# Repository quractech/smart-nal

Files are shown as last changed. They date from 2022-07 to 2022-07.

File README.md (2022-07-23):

# smart Nal
Smart Nal enables ON and OFF functionality for LED ceiling lamp using Bluetooth or normal light switch. <br>

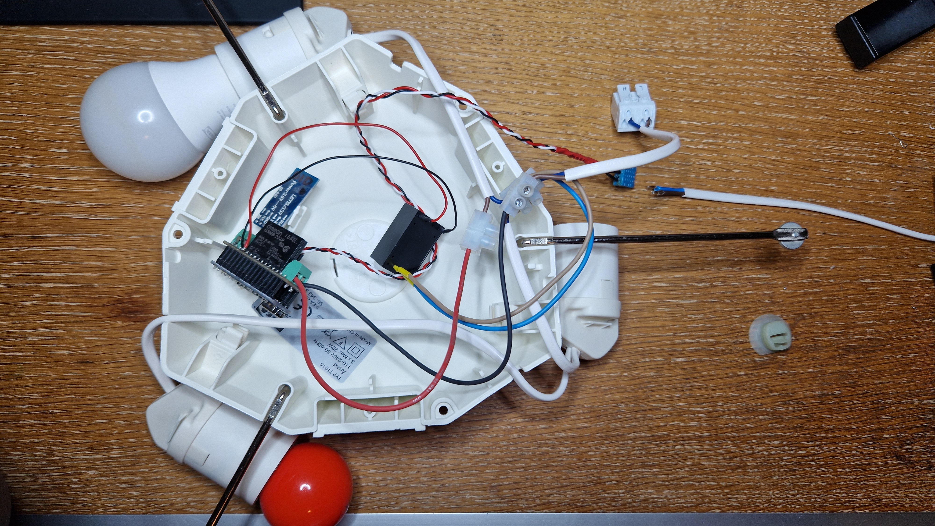
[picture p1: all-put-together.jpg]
image of the Smart Nal Hardware


watch the following YouTube channel for more information. </br>
https://www.youtube.com/embed/videoseries?list=PLivrBlTrqPpaUyPcGpUUAaZgcAJCYTLqt
YouTube Video (https://www.youtube.com/embed/videoseries?list=PLivrBlTrqPpaUyPcGpUUAaZgcAJCYTLqt) </br>

schematic of the Smart Nal Hardware. <br>
https://github.com/quractech/smart-nal/blob/2a30d1d0165a11da4ee4c517b96f4f8cc76464df/smartNal.pdf

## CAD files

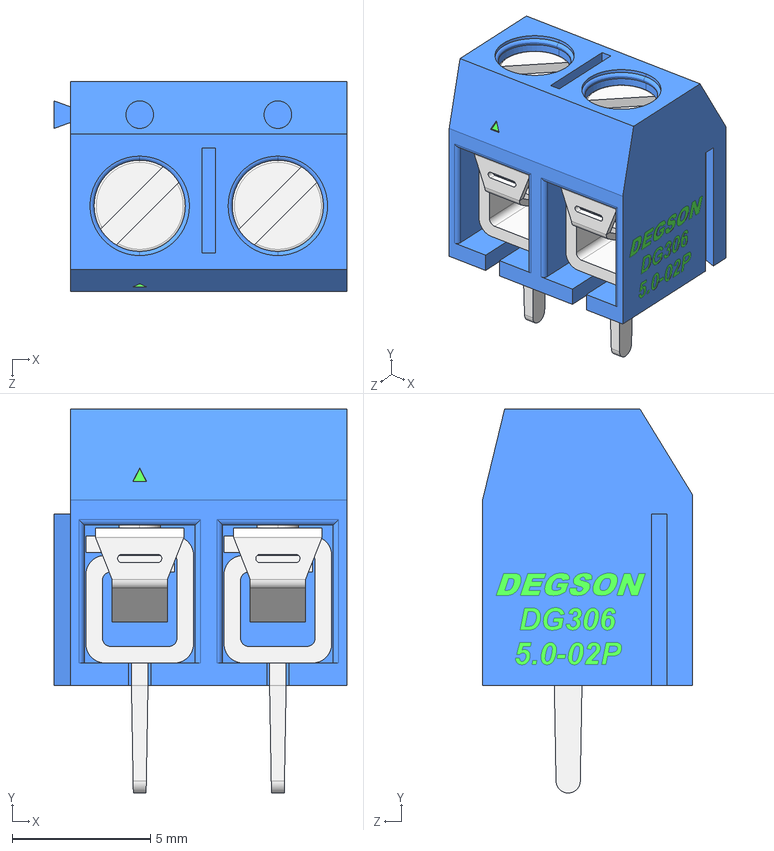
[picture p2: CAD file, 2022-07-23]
Smart Nal/HW/3dModels/DG306-5.0-02P-12-00AH.STEP
10.6 x 13.9 x 7.60 mm

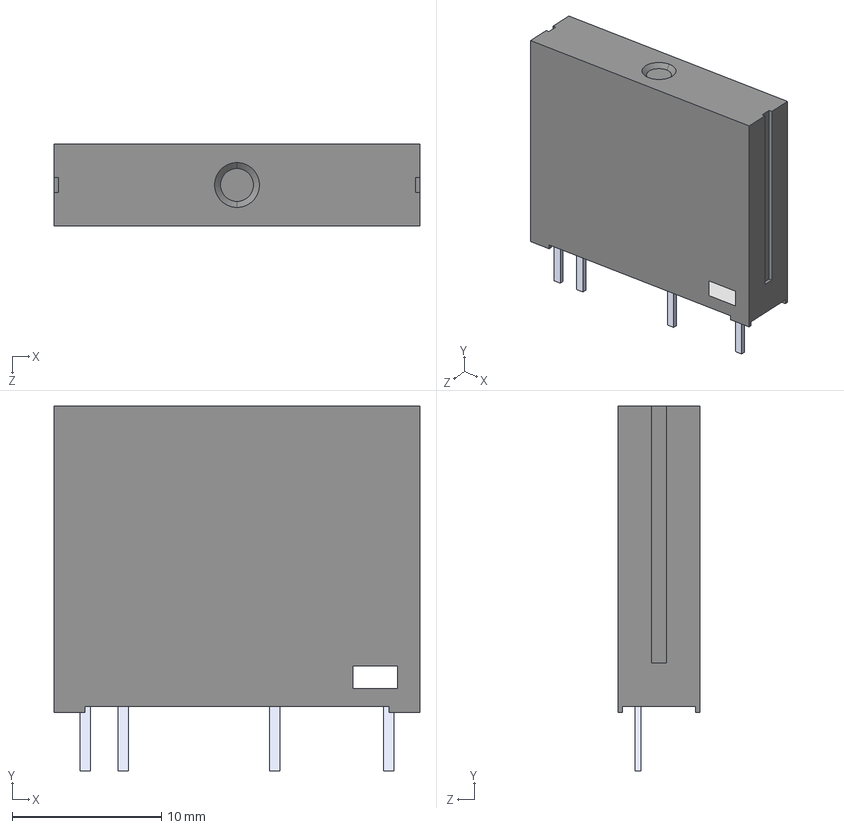
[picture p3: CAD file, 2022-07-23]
Smart Nal/HW/3dModels/G3MB202PDC12.step
24.5 x 24.4 x 5.50 mm

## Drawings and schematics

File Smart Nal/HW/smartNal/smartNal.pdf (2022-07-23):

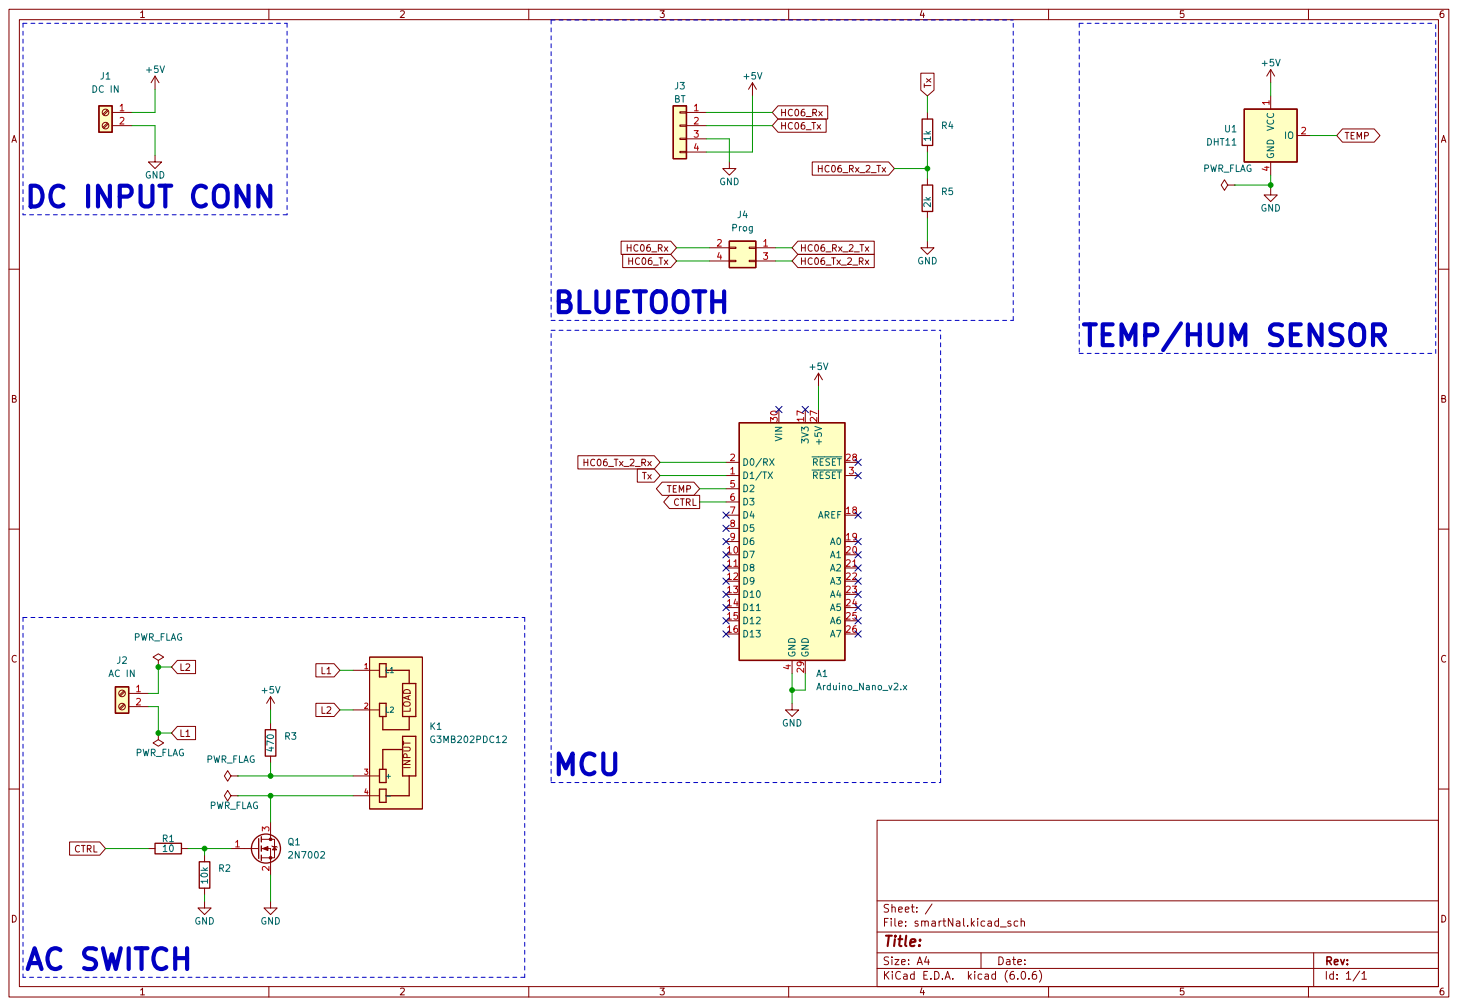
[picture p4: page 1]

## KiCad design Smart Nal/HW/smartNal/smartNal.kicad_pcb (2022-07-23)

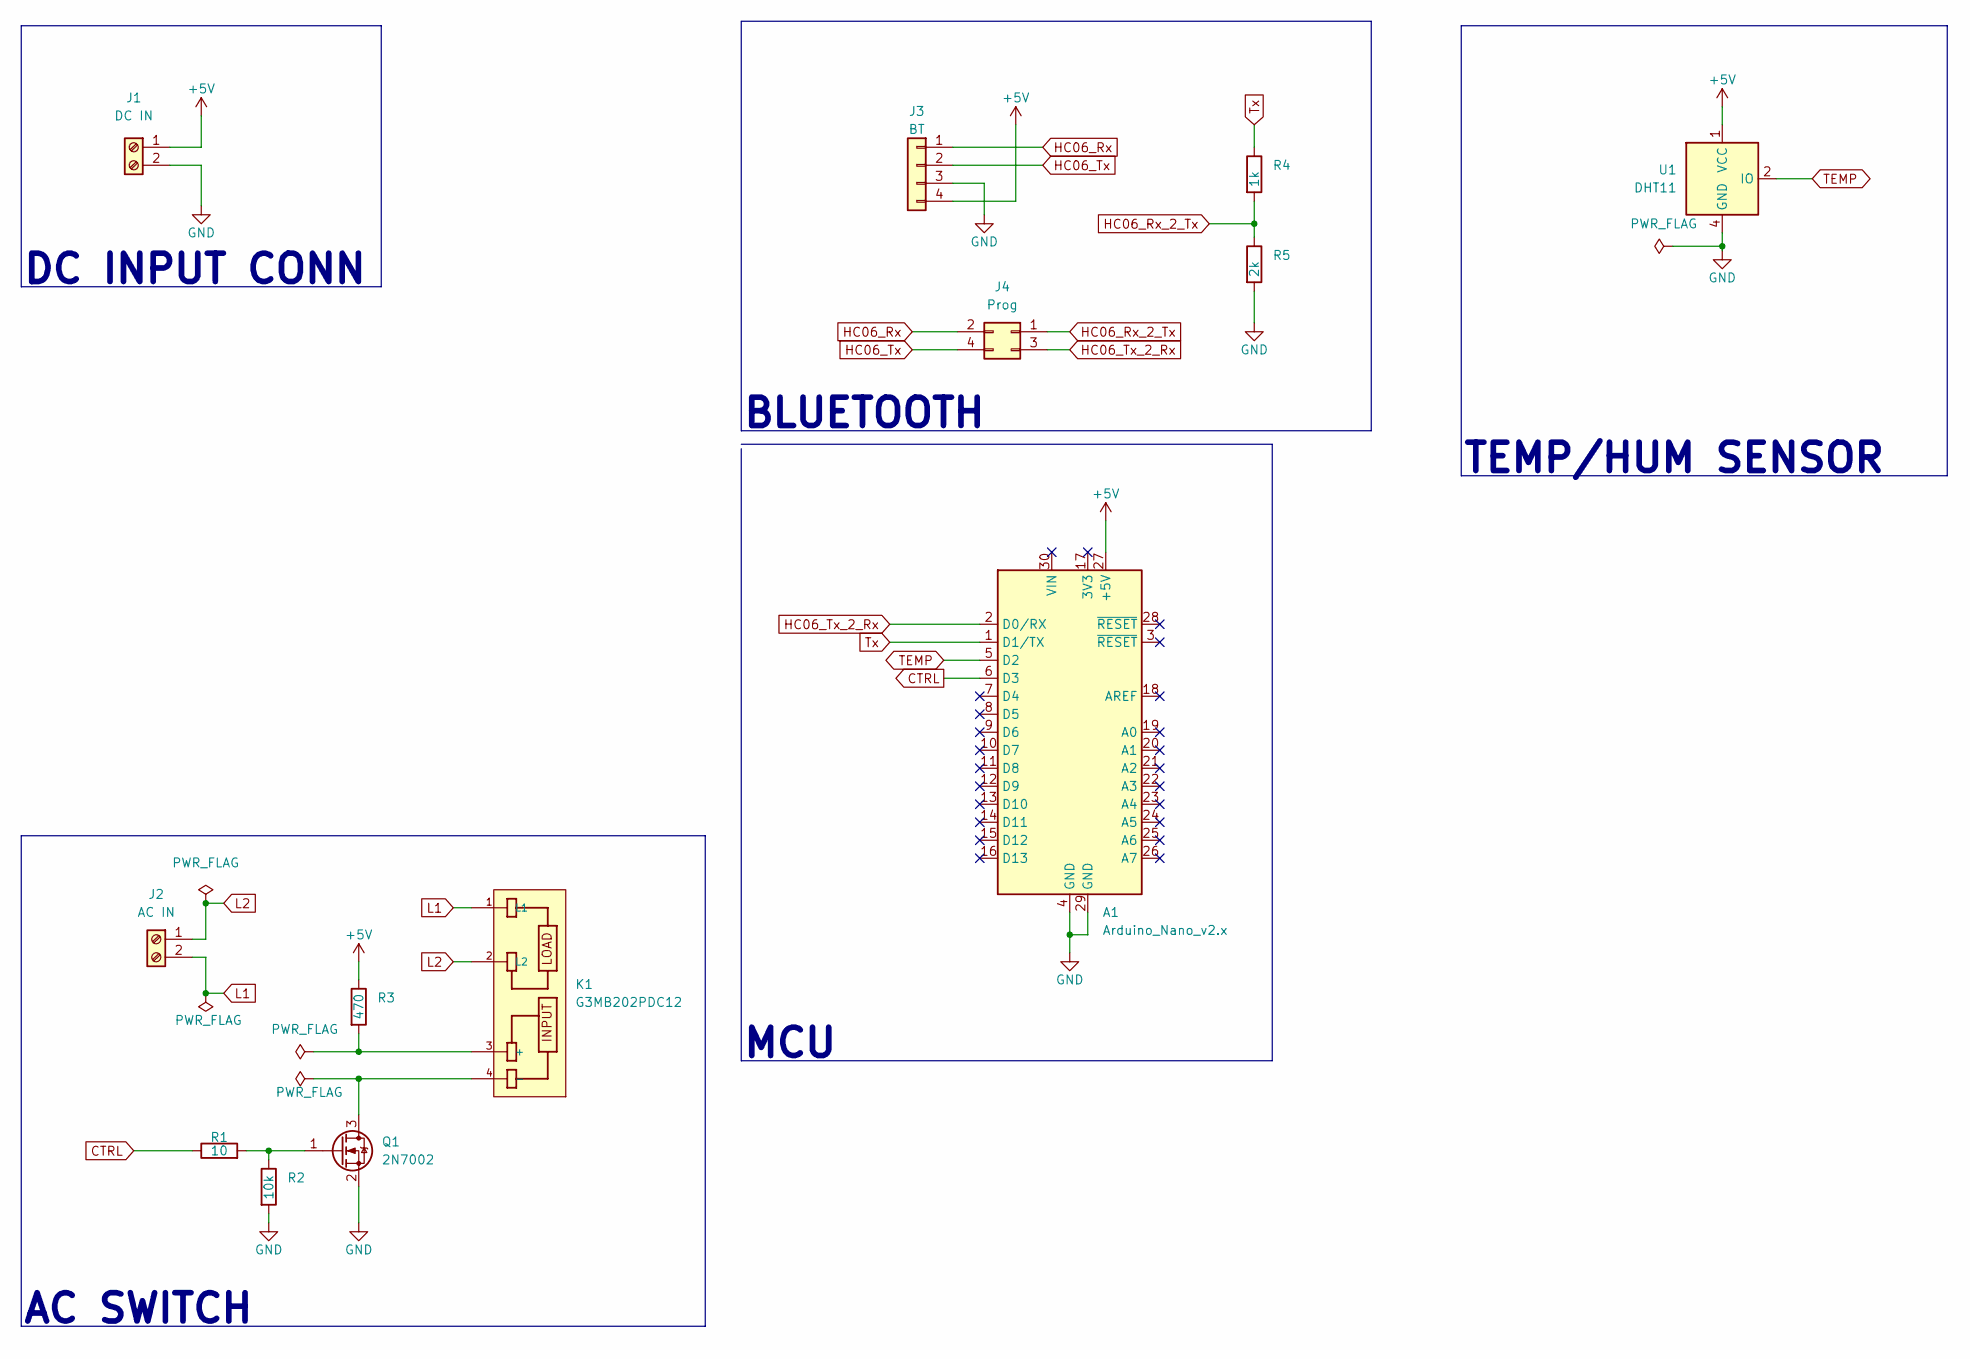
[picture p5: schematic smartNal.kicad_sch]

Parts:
A1: Arduino_Nano_v2.x; Arduino_Nano
J1: DC IN; TerminalBlock_bornier-2_P5.08mm
J2: AC IN; TerminalBlock_bornier-2_P5.08mm
J3: BT; PinHeader_1x04_P2.54mm_Vertical
J4: Prog; PinHeader_2x02_P2.54mm_Vertical
K1: G3MB202PDC12; RELAY_G3MB202PDC12; PARTREV N/A
Q1: 2N7002; SOT-23; MFR.Part # 2N7002; JLCPCB Part # C8545
R1: 10; R_0603_1608Metric
R2: 10k; R_0603_1608Metric
R3: 470; R_0603_1608Metric
R4: 1k; R_0603_1608Metric
R5: 2k; R_0603_1608Metric
U1: DHT11; Aosong_DHT11_5.5x12.0_P2.54mm

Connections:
+5V: A1.27 (+5V), J1.1, J3.4, R3.1, U1.1 (VCC)
CTRL: A1.6 (D3), R1.1
GND: A1.4 (GND), A1.29 (GND), J1.2, J3.3, Q1.2 (S), R2.2, R5.2, U1.4 (GND)
HC06_Rx: J3.1, J4.2
HC06_Rx_2_Tx: J4.1, R4.2, R5.1
HC06_Tx: J3.2, J4.4
HC06_Tx_2_Rx: A1.2 (D0/RX), J4.3
L1: J2.2, K1.1 (L1)
L2: J2.1, K1.2 (L2)
unnamed: K1.3 (+), R3.2
unnamed: K1.4 (-), Q1.3 (D)
unnamed: Q1.1 (G), R1.2, R2.1
TEMP: A1.5 (D2), U1.2 (IO)
Tx: A1.1 (D1/TX), R4.1

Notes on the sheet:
BLUETOOTH
DC INPUT CONN
TEMP/HUM SENSOR
AC SWITCH
MCU

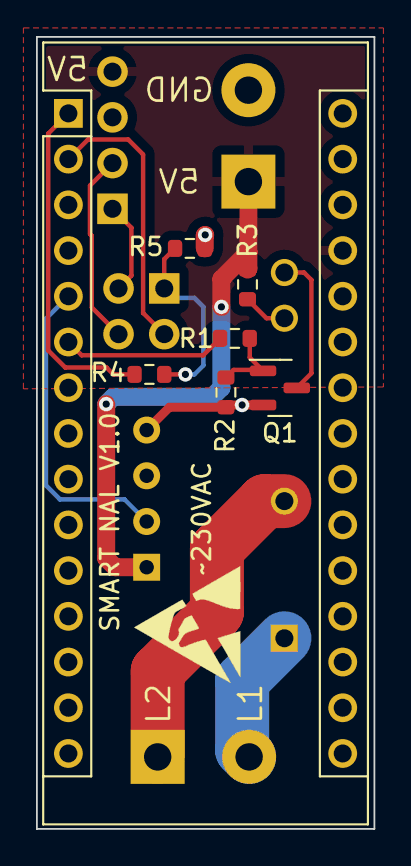
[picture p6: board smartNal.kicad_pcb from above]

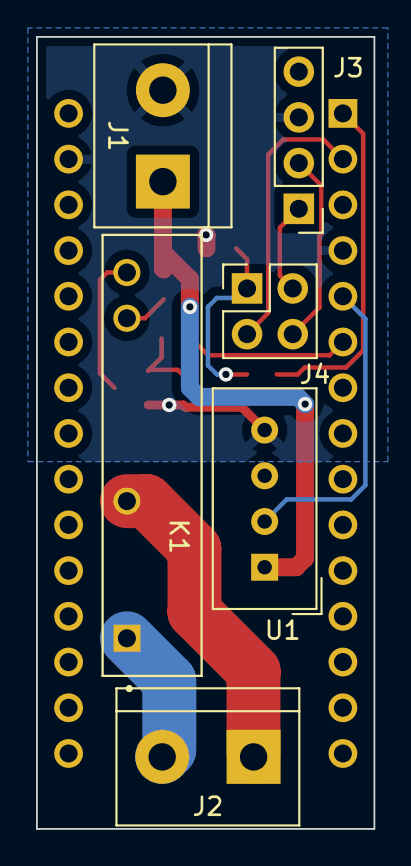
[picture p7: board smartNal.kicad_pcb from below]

Board: 2 copper layers, 18.8 x 44.0 mm, 13 parts (6 on the bottom side), 14 nets.

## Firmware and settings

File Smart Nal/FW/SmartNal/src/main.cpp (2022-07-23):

//#include <Arduino.h>
#include <EEPROM.h>
#include <Adafruit_Sensor.h>
#include <DHT.h>
// #include "LibPrintf.h"
//#include <DHT_U.h>

#define DHTPIN 2 // Digital pin connected to the DHT sensor
//#define DHTTYPE DHT22       // DHT 22  (AM2302), AM2321
#define DHTTYPE DHT11 // DHT 11

#define LEDPin LED_BUILTIN  // Arduino nano buildin LED PIN
#define CTRLPin 3           // Assign D3 to Control
#define EEPROM_ADR 10        // EEPROM ADDRESS 0
#define maxReset 1          // Maximum number of reset

DHT dht(DHTPIN, DHTTYPE);   // Initialize DHT11
volatile uint8_t lightStatus = 0;
volatile unsigned char serialMessage = 0;
volatile uint8_t resetCounter = 0;
float humidityResult = 0;
float tempResult = 0;

void setup()
{
  pinMode(LEDPin, OUTPUT);  // Configure LED Pin as an OUTPUT
  pinMode(CTRLPin, OUTPUT); // Configure controll pin as an OUTPUT
  Serial.begin(9600);        // Start Serial communication
  dht.begin();               // Start DHT11
  digitalWrite(LEDPin, LOW);
  
  resetCounter = EEPROM.read(EEPROM_ADR); // Assign EEPROM value stored in ADDRESS 0 to the variable resetCounter

  resetCounter++;                         // Increament resetCounter
  if (resetCounter > maxReset)
  {
    lightStatus = 1;
    resetCounter = 0;               // set the variable resetCounter to 0
    // digitalWrite(LEDPin, HIGH);
    digitalWrite(CTRLPin, HIGH);
  }
  else
  {
    lightStatus = 0;
    // digitalWrite(LEDPin, LOW);
    digitalWrite(CTRLPin, LOW);
  }
  EEPROM.write(EEPROM_ADR, resetCounter); // Store the new resetCounter to EEPROM
}

void loop()
{
  noInterrupts();
  // critical, time-sensitive code here
  if (lightStatus == 0)
  {
    // digitalWrite(LEDPin, LOW);
    digitalWrite(CTRLPin, LOW);
  }
  else if (lightStatus == 1)
  {
    // digitalWrite(LEDPin, HIGH);
    digitalWrite(CTRLPin, HIGH);
    resetCounter = 0; // set the variable resetCounter to 0
  }
  
  interrupts();
  delay(100);
  humidityResult = dht.readHumidity();    // Read humidity as procent (the default)
  tempResult = dht.readTemperature(); // Read temperature as Celsius (the default)
  EEPROM.write(EEPROM_ADR, resetCounter);
}

// Interrupt on serial event
void serialEvent()
{
  while (Serial.available())
  {
    serialMessage = Serial.read();
  }
  Serial.println();
  Serial.print("Temp=");
  Serial.println(tempResult);
  Serial.print("Hum =");
  Serial.println(humidityResult);

  if (serialMessage == '1')
  {
    lightStatus = 1;
    
  }
  else if (serialMessage == '0')
  {
    lightStatus = 0;
  }
}
